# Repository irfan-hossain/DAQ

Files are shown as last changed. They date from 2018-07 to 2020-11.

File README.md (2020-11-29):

# DAQ: Data Acquisition System
DAQ uses an Arduino Uno to create a high speed data acquisition system. The project is based on the OpenLabTools guide provided by the Univeristy of Cambridge, provided [here](http://openlabtools.eng.cam.ac.uk/Resources/Datalog/RPi_Arduino/). There are a few modifications from the original guide and implementation differences. 

The purpose of this project was to learn and experiment with Arduino registers, work first hand with SPI and I2C devices, and create an ambient acquisition system that displays data on an OLED display. The system uses an FRAM chip as a double buffer system (the chip is split in half to have rx and tx buffers at any given moment). The FRAM and OLED components are both I2C and use the shared I2C bus.    

A possible application is using the data DAQ as a passive sensor display, to show humidity, temperature, light, or any analog sensor value. The project can be expanded upon to stream the data to another device, or visualize the sensor values with a plot on the OLED.

An immensely helpful reference is the Atmel ATmega328/P datasheet, found [here](http://ww1.microchip.com/downloads/en/DeviceDoc/Atmel-42735-8-bit-AVR-Microcontroller-ATmega328-328P_Datasheet.pdf).

# Hardware
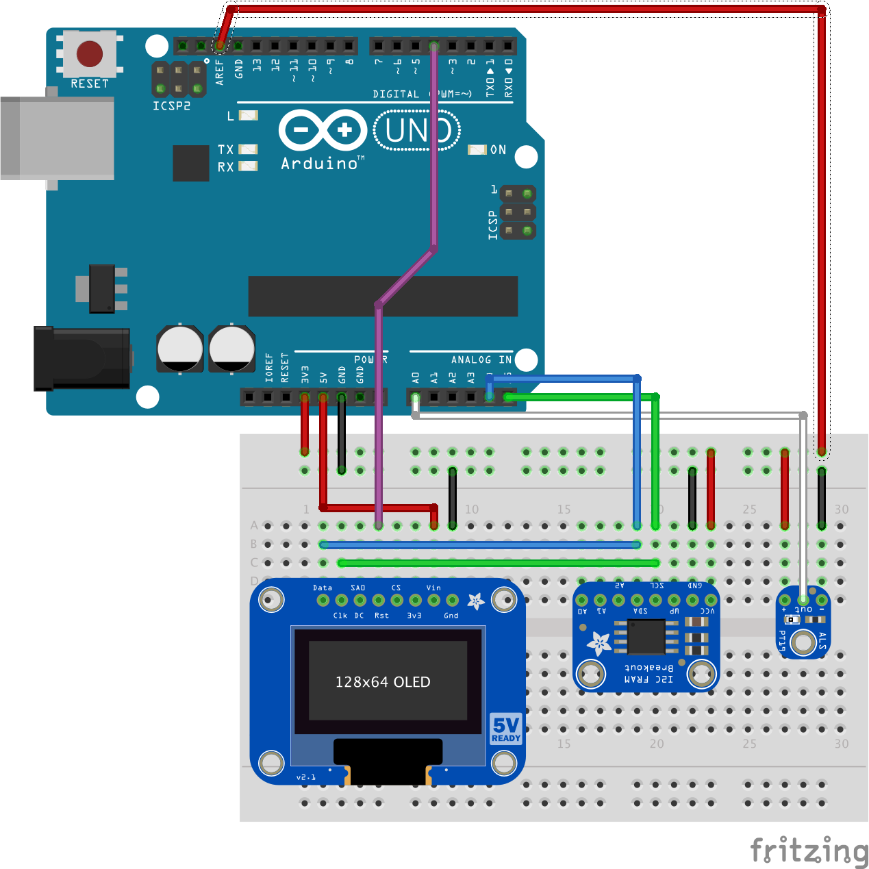
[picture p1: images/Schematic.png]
Fritzing Schematic of Components

   * Arduino Uno
   * Light Sensor (or any sensor with analog output)
   * USB Serial Cable (for Uno)
   * OLED 128x64 I2C display.
   * Adafruit I2C FRAM

# Specifications
The goal for this project is to:
- Sample at a raw rate of 16 KHz. (For a presclaer of 2, the top register should be 1249).
- Use Timer1 Compare Match B (TOP register is ICR1) to trigger a timer interrupt.
- Implement a double buffer using the FRAM chip. As data is being written to one half of the chip, data will be read and displayed to the OLED from the second half of the chip.
- Use analog input A0.
- Set the reference voltage to 3.3 V.
- Use an ADC prescale of 8 to achieve fast ADC conversion speeds (2 MHz).
- Have the ADC result left shifted to achieve an 8-bit result stored in ADCH, rather than combine the default 10-bit result.

# Code Guide
The code guide section is an explanation of some of the firmware choices for this project, and hopefully a reference for others looking to create their own DAQ, or expand and improve upon this design.
### ADMXUX

| 7  | 6  | 5  | 4  | 3  | 2  | 1  | 0  |
|:----:|:----:|:----:|:----:|:----:|:----:|:----:|:----:|
|REFS1|REFS0|ADLAR|--|MUX3|MUX2|MUX1|MUX0|
|0|0|1|--|0|0|0|0|

**[7:6]** Sets the reference voltage. This configuration sets the reference voltage to the AREF pin. For now the 3.3V output pin is connected to AREF.

**[ 5 ]** Left shifts the 10 bit conversion result so the ADCH register contains an 8-bit result from the ADC. Example:
* ADLAR = 0, ADCH = ---- --11, ADCL = 1011 0101
* ADLAR = 1, ADCH = 1110 1101, ADCL = 01-- ---

**[3:0]** Selects the analog pin being used for ADC, this configuration sets the pin to A0.

### ADSCRA
| 7  | 6  | 5  | 4  | 3  | 2  | 1  | 0  |
|:----:|:----:|:----:|:----:|:----:|:----:|:----:|:----:|
|ADEN|ADSC|ADATE|ADIF|ADIE|ADPS2|ADPS1|ADPS0|
|1|X|1|X|X|0|1|1

**[ 7 ]** Enables ADC.

**[ 6 ]** Starts an ADC conversion, not set in the config function, set in the enableInterrupts() function.

**[ 5 ]** Enables auto-triggering of the ADC (in our case Timer1 interrupt is used as the trigger).

**[ 4 ]** This bit set when an ADC conversion is finished, no need to do anything for this bit.

**[ 3 ]** Enables ADC interrupt, set in enableInterrupts() function.

**[2:0]** Sets prescaler of ADC clock, this configuration sets the presclaer to 8.

### ADCSRB
| 7  | 6  | 5  | 4  | 3  | 2  | 1  | 0  |
|:----:|:----:|:----:|:----:|:----:|:----:|:----:|:----:|
|--|ACME|--|--|--|ADTS2|ADTS1|ADTS0|
|--|0|--|--|--|1|0|1|

**[ 7 ]** Reserved.

**[ 6 ]** Analog Comparator Multiplexor. This bit is not used and set to zero.

**[5:3]** Reserved.

**[2:0]** Sets the ADC auto trigger source. In this case we have chosen Timer1, Compare Match B.

### TCCR1A
| 7  | 6  | 5  | 4  | 3  | 2  | 1  | 0  |
|:----:|:----:|:----:|:----:|:----:|:----:|:----:|:----:|
|COM1|COM1|COM1|COM1|--|--|WGM11|WGM10|
|0|0|0|0|--|--|0|0

**[7:4]** Not using these bits, set to zero.

**[3:2]** Reserved.

**[1:0]** These bits are the first part of selecting the compare match mode and top register. This configuration is for selecting compare match B, top register is ICR1.

### TCCR1B
| 7  | 6  | 5  | 4  | 3  | 2  | 1  | 0  |
|:----:|:----:|:----:|:----:|:----:|:----:|:----:|:----:|
|ICNC1|ICES1|--|WGM13|WGM12|CS12|CS11|CS10|
|0|0|--|0|1|1|0|1|

**[7:6]** Not used, set to zero.

**[4:3]** These bits are the second part of selecting the compare match mode and top register. This configuration is for selecting compare match B, top register is ICR1.

**[2:0]** Sets prescaler for timer, this configuration set's the prescaler to 8.

### ICR1

ICR1 = 1249

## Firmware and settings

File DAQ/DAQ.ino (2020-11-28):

///////////////////////////////////////////////////////////////////////////////
//`File: DAQ.ino
// Desc: Main loop for arduino code to run.
//
//
// Author: Irfan Hossain
///////////////////////////////////////////////////////////////////////////////
#include "Wire.h"
#include "isr.h"
#include "register.h"
#include "fram.h"
#include "oledDisplay.h"

#define BAUD_RATE 250000
#define SPLASH_X 33
#define SPLASH_Y 13
#define SPLASH_DELAY 5000

static const uint8_t  STATUS_LED_PIN = LED_BUILTIN; // LED for transmission status
static const uint8_t  START_BYTE     = 0x42; // Start sampling if read from Pi
static const uint8_t  END_BYTE       = 0x45; // End sampling if read from Pi

void setup()
{
  /////////////////////////////////////////
  /// Setup registers for sampling.
  setupRegisters();

  /////////////////////////////////////////
  /// Setup OLED display.
  setupOLED(SPLASH_X, SPLASH_Y, SPLASH_DELAY);
  
  /////////////////////////////////////////
  /// Setup Serial Communication
  Serial.begin(115200);

  /////////////////////////////////////////
  /// Setup FRAM chips.
  beginFRAM();

  /////////////////////////////////////////
  /// Setup LED.
  pinMode(STATUS_LED_PIN, OUTPUT);
}

void loop()
{
    txBuffer();
}

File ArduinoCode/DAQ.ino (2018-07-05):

void setup()
{
  // Start serial communication.
  Serial.begin(250000);
}


void loop()
{
    // Check to see if there is data in serial buffer.
    if (Serial.available)
    {
      // Read data from serial buffer and write it back over
      // serial connection.
      Serial.write(Serial.read());
    }
}

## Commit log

2018-07-13 DAQ-1000 Added empty files to start working on Arduino code.
2018-07-14 DAQ-1000 Backup changes made (started on Arduino code).
2018-07-15 DAQ-1000 Register and interrupt configuration, testing the functions by print sensor data to serial monitor.
2018-08-21 DAQ-1001 Attempt to fix error where ADCH only outputs a value of 255. I'm following the tutorial exactly with a frequency of 1 Hz, so the comments don't match the code exactly. This commit isn't work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
2018-10-04 DAQ-1002 Lost project notebook, reverted project back to my own design specs (100 KHz sampling). Still have issue with ADCH stuck at 255.
    [DAQ.ino]
2018-10-05 DAQ-1001 Added code to set and print data_byte.
2018-10-06 DAQ-1001 Solved issue of why value is stuck at 255, it was because analog reference voltage was set to AREF, and nothing was connected (hardware issue). This commit updates comments and readme.
    [Schematic.fzz]
2018-10-09 DAQ-1002 Edited schematic picture and updated readme.
    [Schematic.fzz]
2018-11-23 DAQ-2001 OLED display is added and displays sensor data. Also updated schematic.
    [Schematic.fzz]
2018-12-09 DAQ-1000 Folder reorganization and putting in groundwork for pushbuttons.
    [Schematic.fzz]
2019-01-05 DAQ-1004 Added hw debouncing for pushbutton.
    [Schematic.fzz]
2019-01-09 DAQ-1000 Code organization and cleanup
    [Schematic.fzz]
2019-01-25 DAQ-1004 Removed pushbutton code and hardware.
    [Schematic.fzz]
2020-01-02 DAQ-1003 Implemented FRAM and SPI. Not tested on target.
2020-01-02 DAQ-1000 Implemented SPI, LED, FRAM, and buffers. Not tested on targert.
2020-11-28 DAQ-2001 Removed SPI-Pi code to be up to spec. Re-added OLED.
2020-11-29 DAQ-1000 Updated readme, minor code comment edits, and updated Fritizing diagram.
    [Schematic.fzz]
